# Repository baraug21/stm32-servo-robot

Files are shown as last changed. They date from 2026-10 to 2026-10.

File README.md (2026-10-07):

# Servo-Driven Robot (WIP)

> **Project Status: Work in Progress**
> This project is currently under active development as a team project. 
> Hardware design (schematics and PCB layout) is completed, while the firmware implementation (motor drivers and user interface) is currently being written.

## Overview
A custom robotic platform featuring servo motor control (PWM) and a matrix keypad interface...

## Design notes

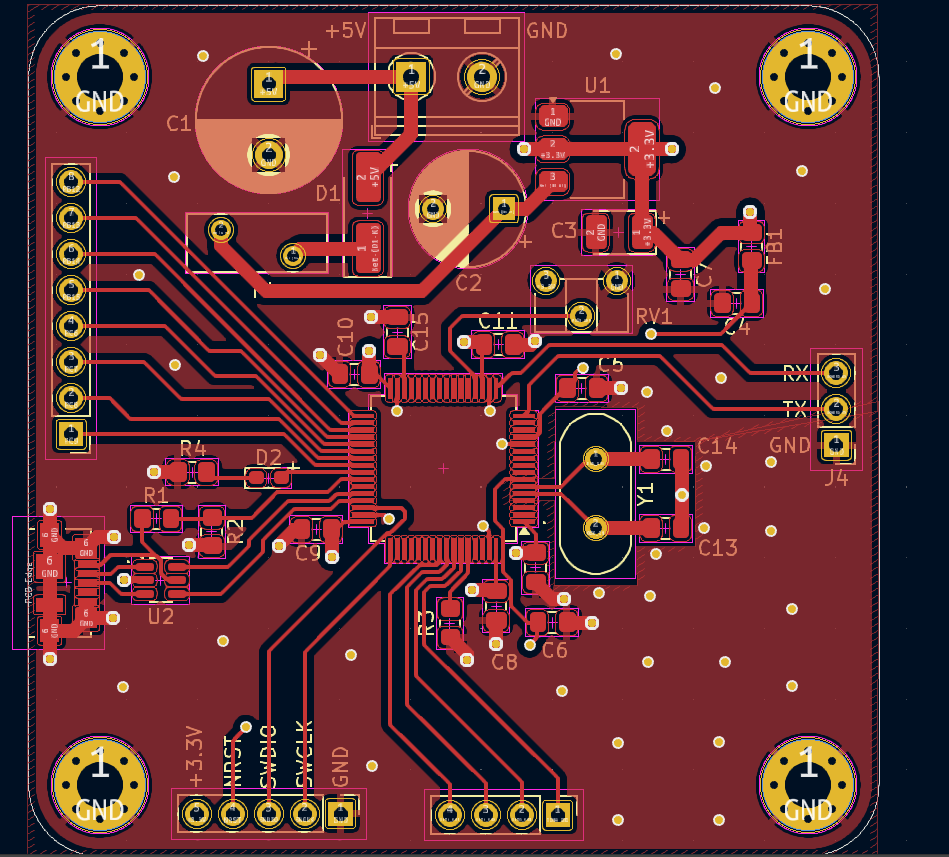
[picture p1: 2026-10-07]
hardware/PCB-front-layer.png

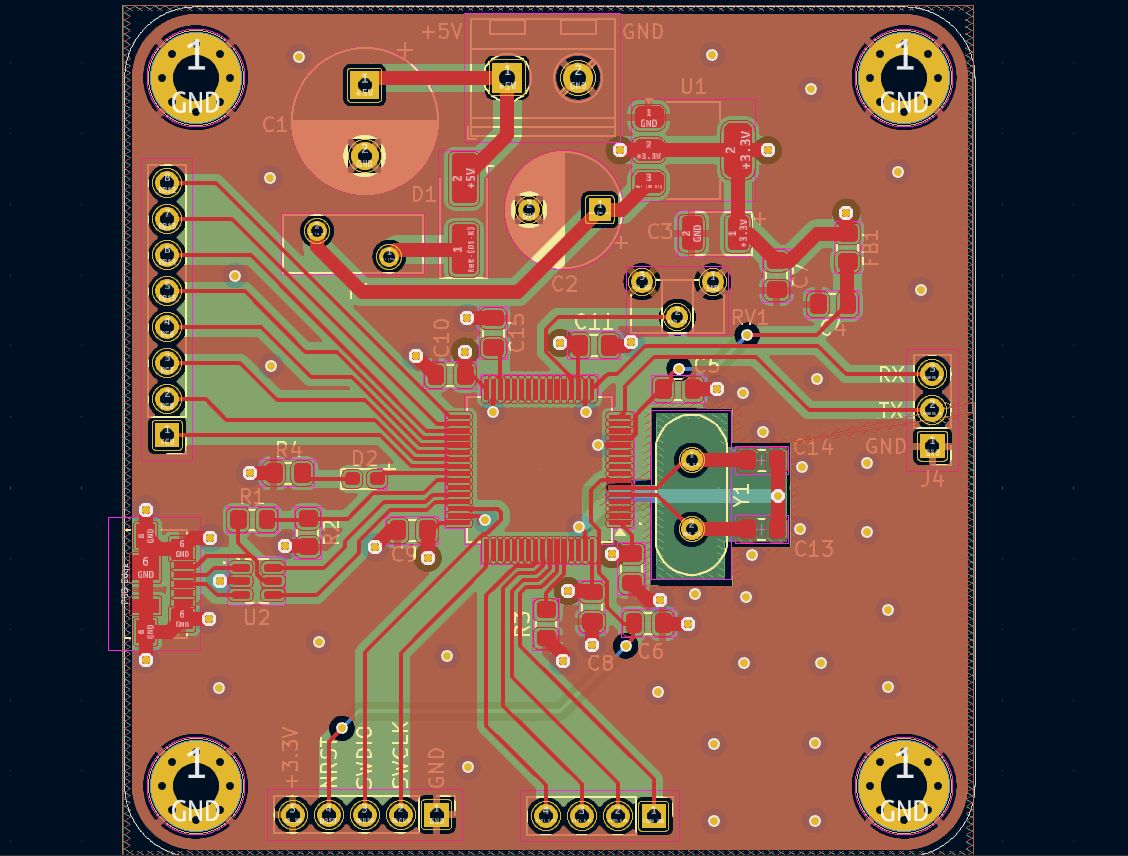
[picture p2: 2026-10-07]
hardware/PCB-all-layers.png

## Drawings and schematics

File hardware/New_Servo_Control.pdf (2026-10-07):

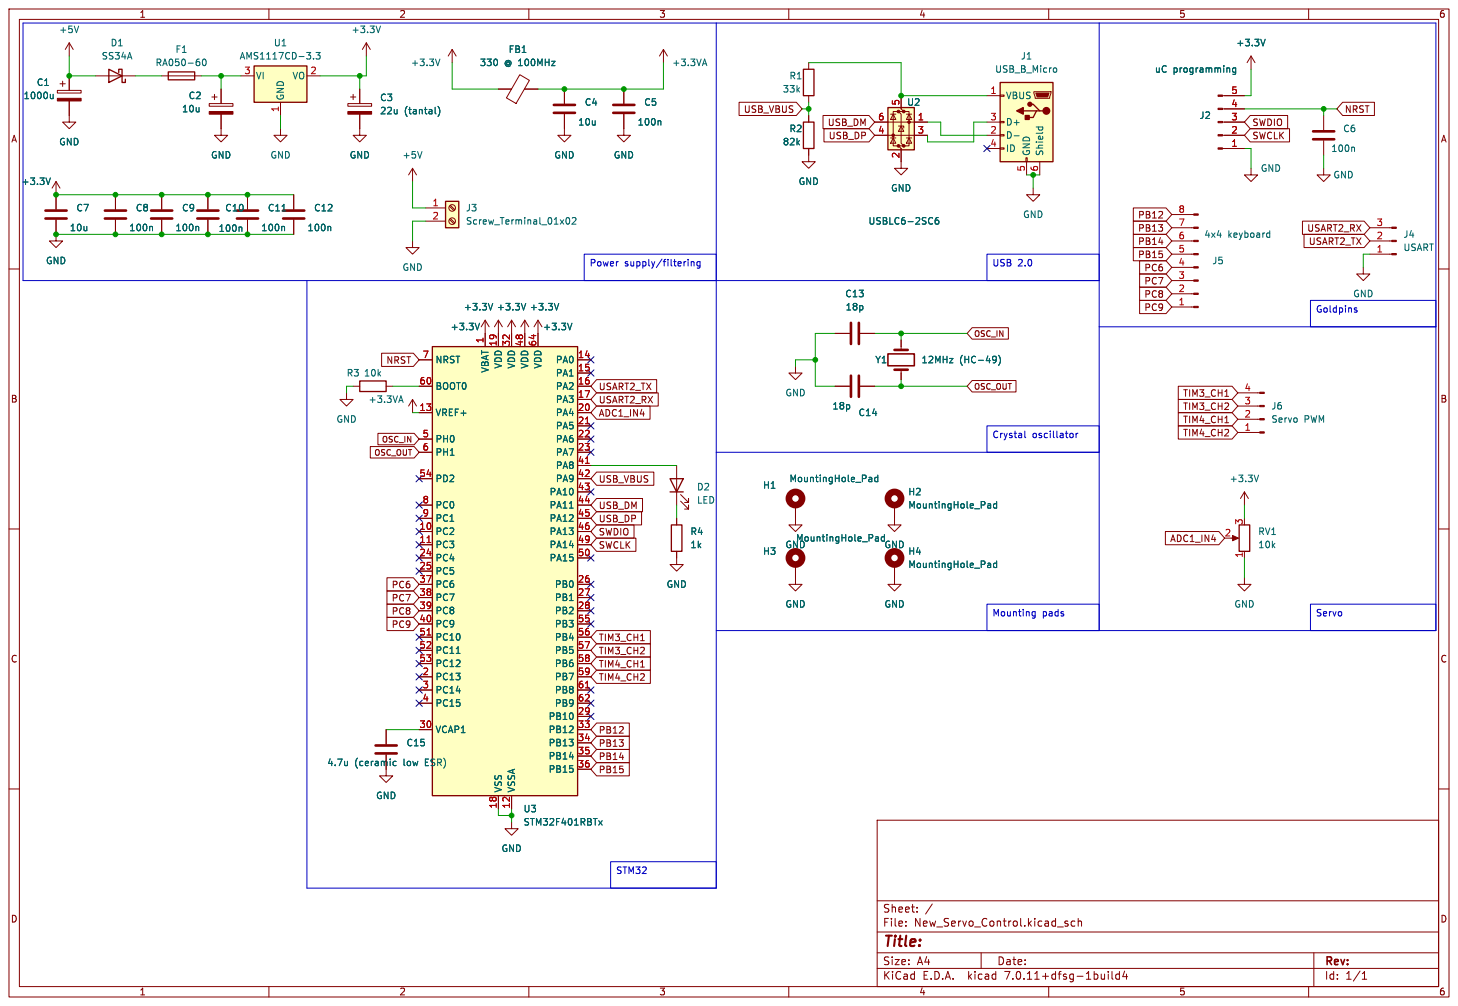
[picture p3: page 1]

1 PC2 10 PC3 11 VSSA 12 VREF+ 13 PA0 14 PA1 15 PA2 16 PA3 17 VSS 18 VDD 19 PC13 2 PA4 20 PA5 21 PA6 22 PA7 23 PC4 24 PC5 25 PB0 26 PB1 27 PB2 28 PB10 29 PC14 3 VCAP1 30 VDD 32 PB12 33 PB13 34 PB14 35 PB15 36 PC6 37 PC7 38 PC8 39 PC15 4 PC9 40 PA8 41 PA9 42 PA10 43 PA11 44 PA12 45 PA13 46 VDD 48 PA14 49 PH0 5 PA15 50 PC10 51 PC11 52 PC12 53 PD2 54 PB3 55 PB4 56 PB5 57 PB6 58 PB7 59 PH1 6 BOOT0 60 PB8 61 PB9 62 VDD 64 NRST 7 PC0 8 PC1 9 C15

1 PC2 10 PC3 11 VSSA 12 VREF+ 13 PA0 14 PA1 15 PA2 16 PA3 17 VSS 18 VDD 19 PC13 2 PA4 20 PA5 21 PA6 22 PA7 23 PC4 24 PC5 25 PB0 26 PB1 27 PB2 28 PB10 29 PC14 3 VCAP1 30 VDD 32 PB12 33 PB13 34 PB14 35 PB15 36 PC6 37 PC7 38 PC8 39 PC15 4 PC9 40 PA8 41 PA9 42 PA10 43 PA11 44 PA12 45 PA13 46 VDD 48 PA14 49 PH0 5 PA15 50 PC10 51 PC11 52 PC12 53 PD2 54 PB3 55 PB4 56 PB5 57 PB6 58 PB7 59 PH1 6 BOOT0 60 PB8 61 PB9 62 VDD 64 NRST 7 PC0 8 PC1 9 U3STM32F401RBTx

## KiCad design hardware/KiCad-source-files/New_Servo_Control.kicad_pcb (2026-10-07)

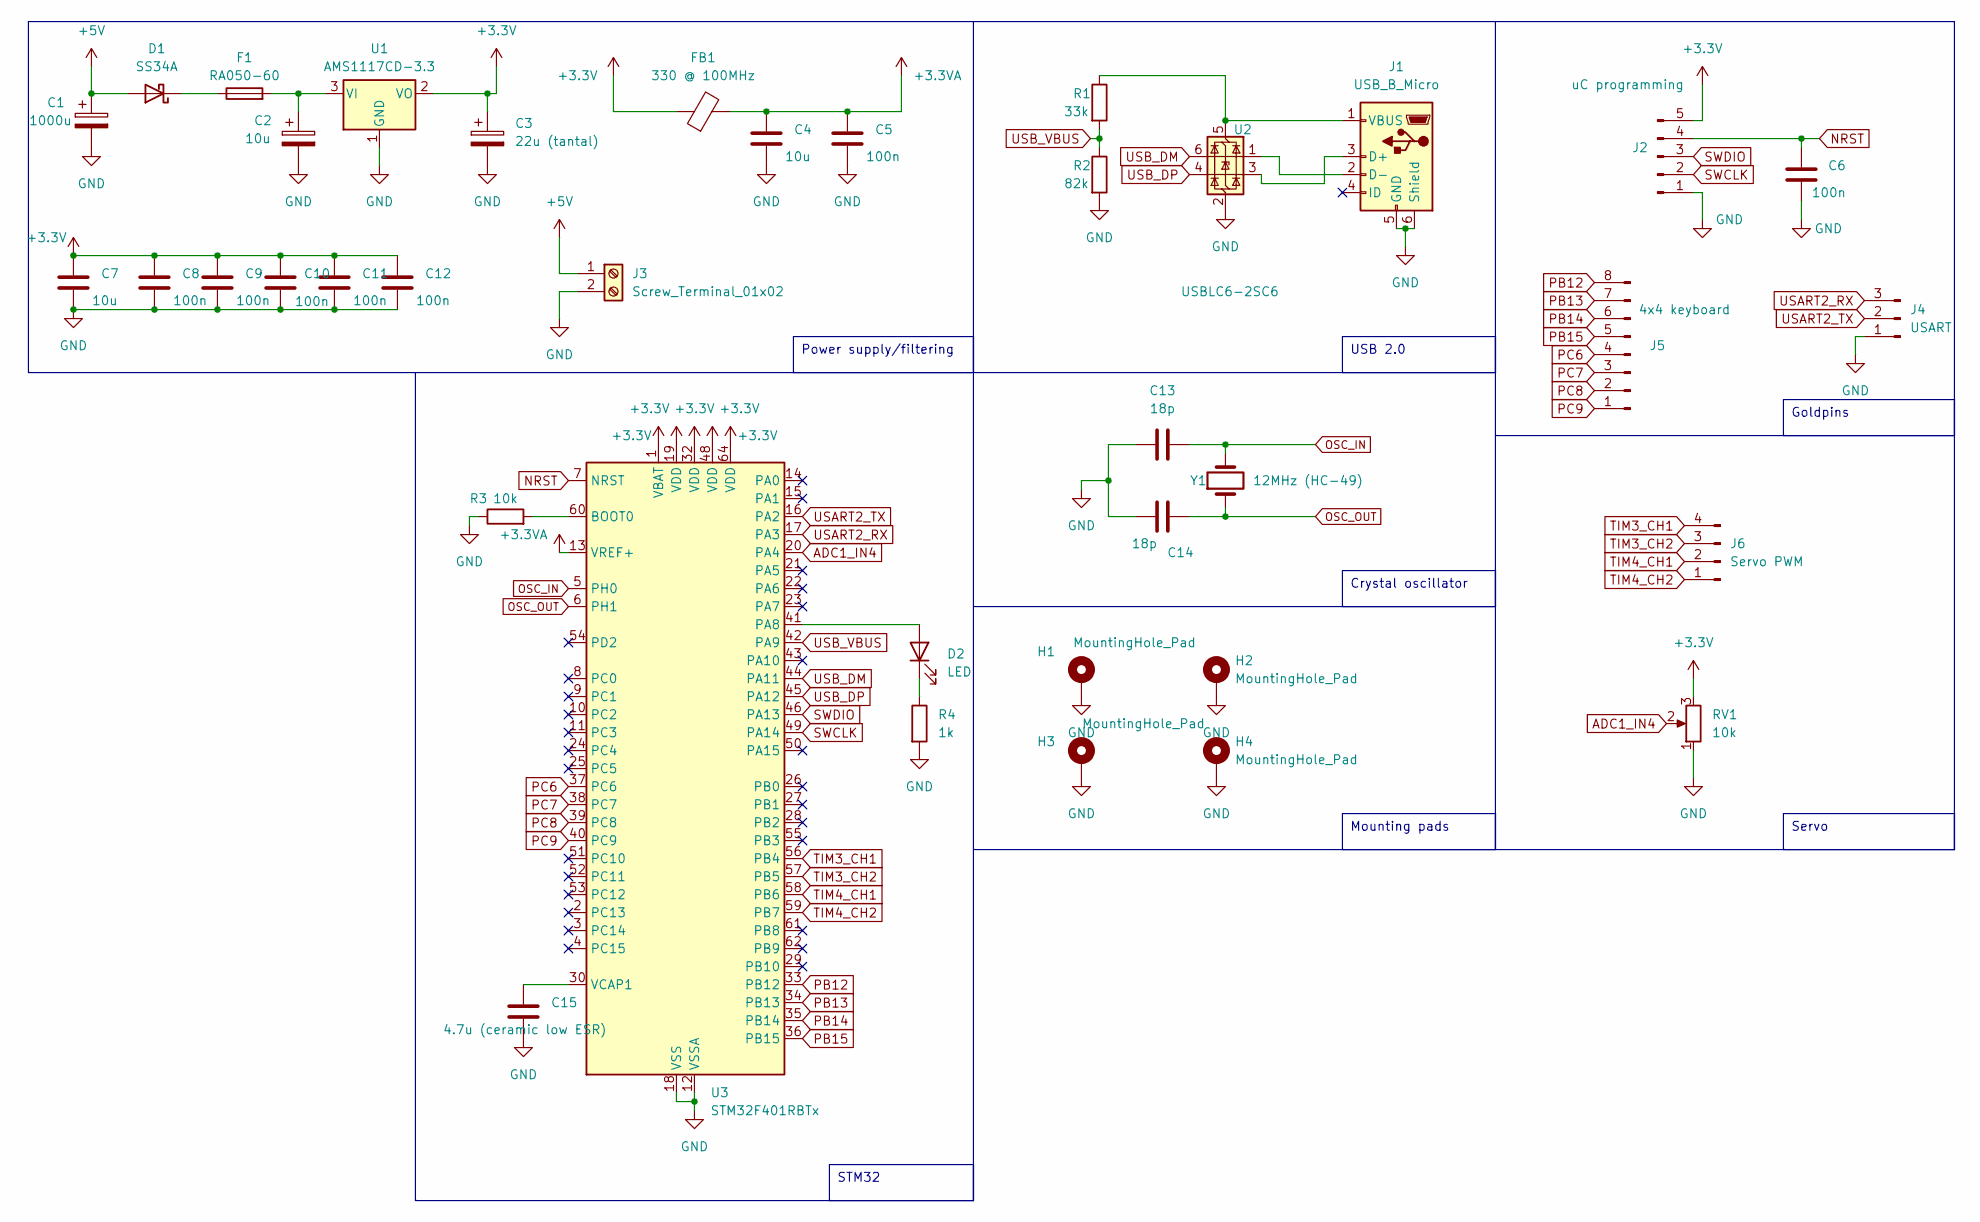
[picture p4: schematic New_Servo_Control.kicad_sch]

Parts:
C1: 1000u; CP_Radial_D10.0mm_P5.00mm
C2: 10u; CP_Radial_D8.0mm_P5.00mm
C3: 22u (tantal); CP_EIA-3528-12_Kemet-T_Pad1.50x2.35mm_HandSolder
C4, C7: 10u; C_0805_2012Metric_Pad1.18x1.45mm_HandSolder
C5, C6, C8, C9, C10, C11, C12: 100n; C_0805_2012Metric_Pad1.18x1.45mm_HandSolder
C13, C14: 18p; C_0805_2012Metric_Pad1.18x1.45mm_HandSolder
C15: 4.7u (ceramic low ESR); C_0805_2012Metric_Pad1.18x1.45mm_HandSolder
D1: SS34A; D_SMA_Handsoldering
D2: LED; LED_0603_1608Metric_Pad1.05x0.95mm_HandSolder
F1: RA050-60; Fuse_BelFuse_0ZRE0025FF_L9.6mm_W3.8mm
FB1: 330 @ 100MHz; R_0805_2012Metric_Pad1.20x1.40mm_HandSolder
H1, H2, H3, H4: MountingHole_Pad; MountingHole_3.2mm_M3_Pad_Via
J1: USB_B_Micro; USB_Micro-B_Molex_47346-0001
J2: uC programming; PinHeader_1x05_P2.54mm_Vertical
J3: Screw_Terminal_01x02; TerminalBlock_RND_205-00045_1x02_P5.00mm_Horizontal
J4: USART; PinHeader_1x03_P2.54mm_Vertical
J5: 4x4 keyboard; PinHeader_1x08_P2.54mm_Vertical
J6: Servo PWM; PinHeader_1x04_P2.54mm_Vertical
R1: 33k; R_0805_2012Metric_Pad1.20x1.40mm_HandSolder
R2: 82k; R_0805_2012Metric_Pad1.20x1.40mm_HandSolder
R3: 10k; R_0805_2012Metric_Pad1.20x1.40mm_HandSolder
R4: 1k; R_0805_2012Metric_Pad1.20x1.40mm_HandSolder
RV1: 10k; Potentiometer_Piher_PT-6-H_Horizontal
U1: AMS1117CD-3.3; SOT-223-3_TabPin2
U2: USBLC6-2SC6; SOT-23-6
U3: STM32F401RBTx; LQFP-64_10x10mm_P0.5mm
Y1: 12MHz (HC-49); Crystal_HC49-U_Vertical

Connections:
+3.3V: C3.1, C7.1, C8.1, C9.1, C10.1, C11.1, C12.1, FB1.1, J2.5, RV1.3, U1.2 (VO), U3.1 (VBAT), U3.19 (VDD), U3.32 (VDD), U3.48 (VDD), U3.64 (VDD)
+3.3VA: C4.1, C5.1, FB1.2, U3.13 (VREF+)
+5V: C1.1, D1.2 (A), J3.1
ADC1_IN4: RV1.2, U3.20 (PA4)
GND: C1.2, C2.2, C3.2, C4.2, C5.2, C6.2, C7.2, C8.2, C9.2, C10.2, C11.2, C12.2, C13.1, C14.1, C15.1, H1.1, H2.1, H3.1, H4.1, J1.5 (GND), J1.6 (Shield), J2.1, J3.2, J4.1, R2.2, R3.1, R4.2, RV1.1, U1.1 (GND), U2.2 (GND), U3.12 (VSSA), U3.18 (VSS), U3.31 (VSS), U3.47 (VSS), U3.63 (VSS)
NRST: C6.1, J2.4, U3.7 (NRST)
unnamed: D1.1 (K), F1.1
unnamed: D2.2 (A), U3.41 (PA8)
unnamed: D2.1 (K), R4.1
unnamed: J1.3 (D+), U2.3 (I/O2)
unnamed: J1.2 (D-), U2.1 (I/O1)
unnamed: J1.1 (VBUS), R1.1, U2.5 (VBUS)
unnamed: C2.1, F1.2, U1.3 (VI)
unnamed: R3.2, U3.60 (BOOT0)
unnamed: C15.2, U3.30 (VCAP1)
OSC_IN: C13.2, U3.5 (PH0), Y1.2
OSC_OUT: C14.2, U3.6 (PH1), Y1.1
PB12: J5.8, U3.33 (PB12)
PB13: J5.7, U3.34 (PB13)
PB14: J5.6, U3.35 (PB14)
PB15: J5.5, U3.36 (PB15)
PC6: J5.4, U3.37 (PC6)
PC7: J5.3, U3.38 (PC7)
PC8: J5.2, U3.39 (PC8)
PC9: J5.1, U3.40 (PC9)
SWCLK: J2.2, U3.49 (PA14)
SWDIO: J2.3, U3.46 (PA13)
TIM3_CH1: J6.4, U3.56 (PB4)
TIM3_CH2: J6.3, U3.57 (PB5)
TIM4_CH1: J6.2, U3.58 (PB6)
TIM4_CH2: J6.1, U3.59 (PB7)
USART2_RX: J4.3, U3.17 (PA3)
USART2_TX: J4.2, U3.16 (PA2)
USB_DM: U2.6 (I/O1), U3.44 (PA11)
USB_DP: U2.4 (I/O2), U3.45 (PA12)
USB_VBUS: R1.2, R2.1, U3.42 (PA9)

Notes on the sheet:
Mounting pads
Power supply/filtering
Crystal oscillator
USB 2.0
STM32
Goldpins
Servo

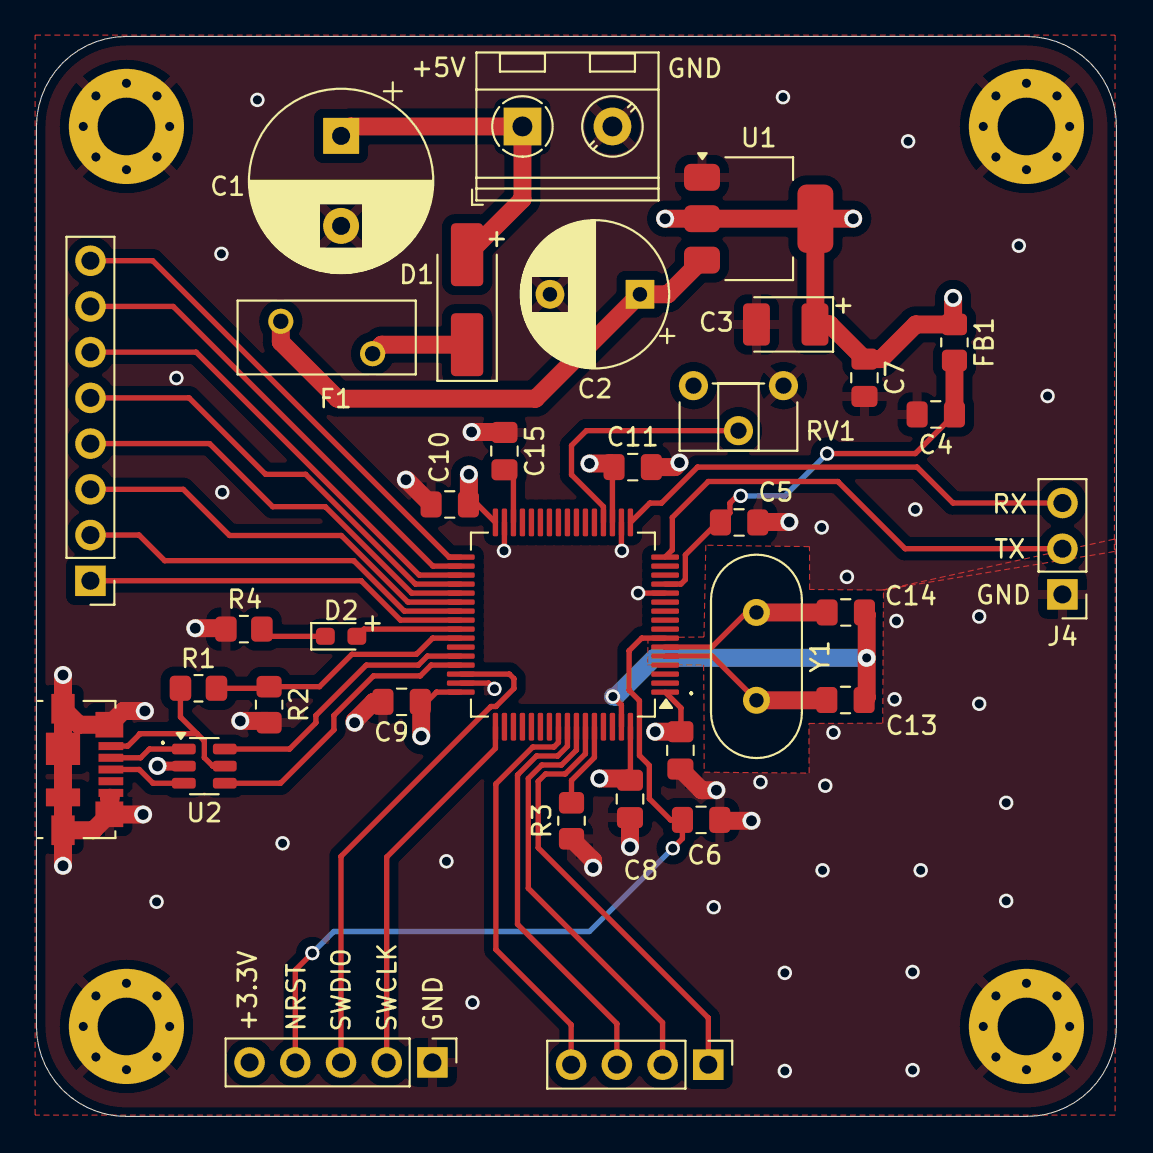
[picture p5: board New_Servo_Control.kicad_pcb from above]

Board: 4 copper layers, 60.0 x 60.0 mm, 38 parts (0 on the bottom side), 36 nets.
